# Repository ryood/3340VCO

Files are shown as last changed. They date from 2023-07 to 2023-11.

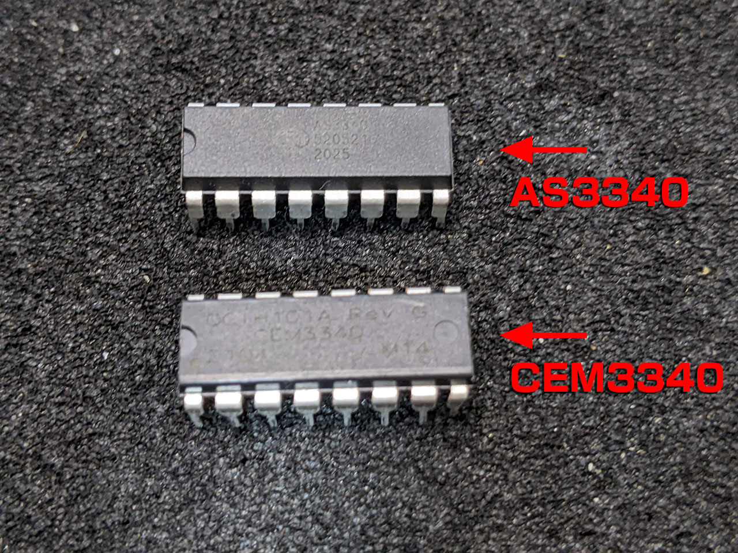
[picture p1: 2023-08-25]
3340VCO性能測定/AS3340_CEM3340.jpg

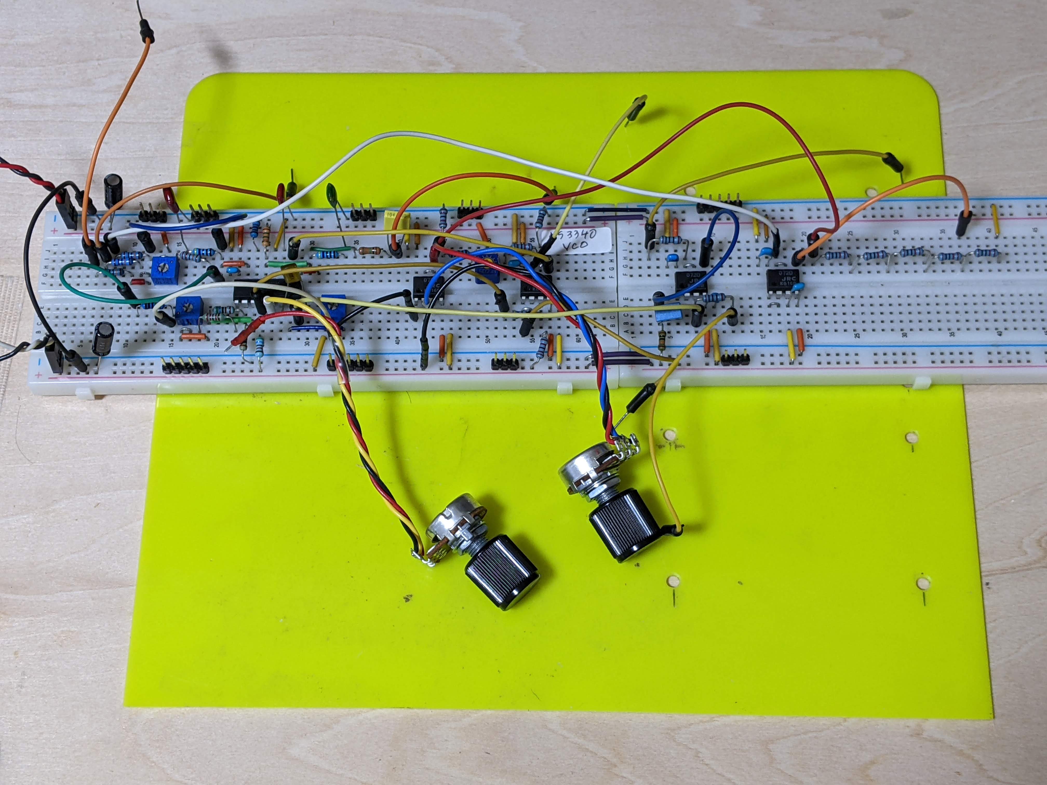
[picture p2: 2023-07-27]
etc/PXL_20230715_095748776.jpg

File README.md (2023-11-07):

# 3340VCO

AS3340/CEM3340を使用したアナログVCOです。

## 機能概要

電源入力 ±12V (Eurorack電源 10Pin)

### コントロール
FINE:  -0.5オクターブ～+0.5オクターブ連続可変

OCTAVE:  +0オクターブ～+4オクターブ切り替え

MOD:  モジュレーション・レベル

PWM:  PWMレベル調整 (PULSE_WIDTH設定値～PWM入力)

PULSE_WIDTH:  パルス幅調整

### 入出力
CV_IN:  CV入力

MOD_IN:  モジュレーション入力

PWM_IN:  PWM入力

OUT:  音声出力

入力信号電圧: -5V～+5V　出力信号振幅: -4V～+4V 

## 参考記事
[音源とオーディオの電子工作（予定）：3340VCO](https://dad8893.blogspot.com/search/label/3340VCO)

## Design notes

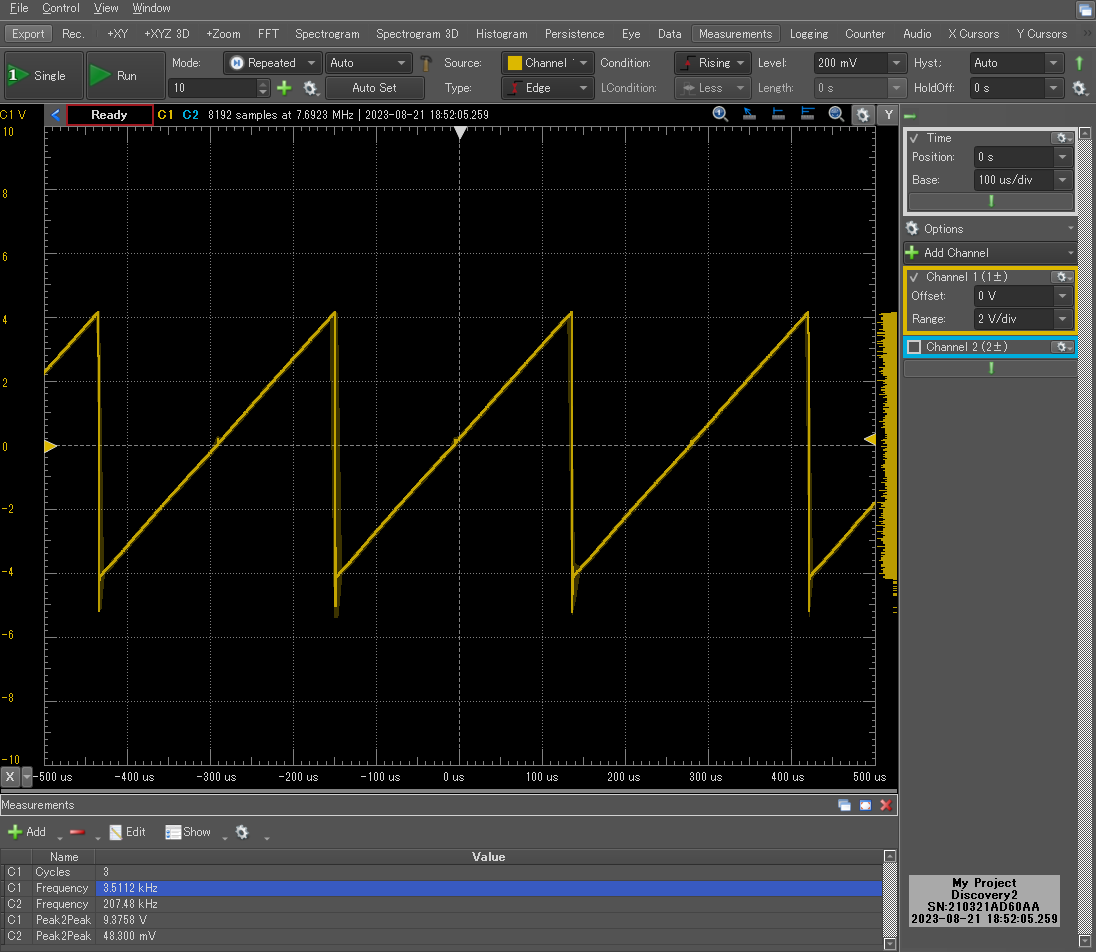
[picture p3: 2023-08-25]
3340VCO性能測定/3340VCO_SAW_3.52kHz.png

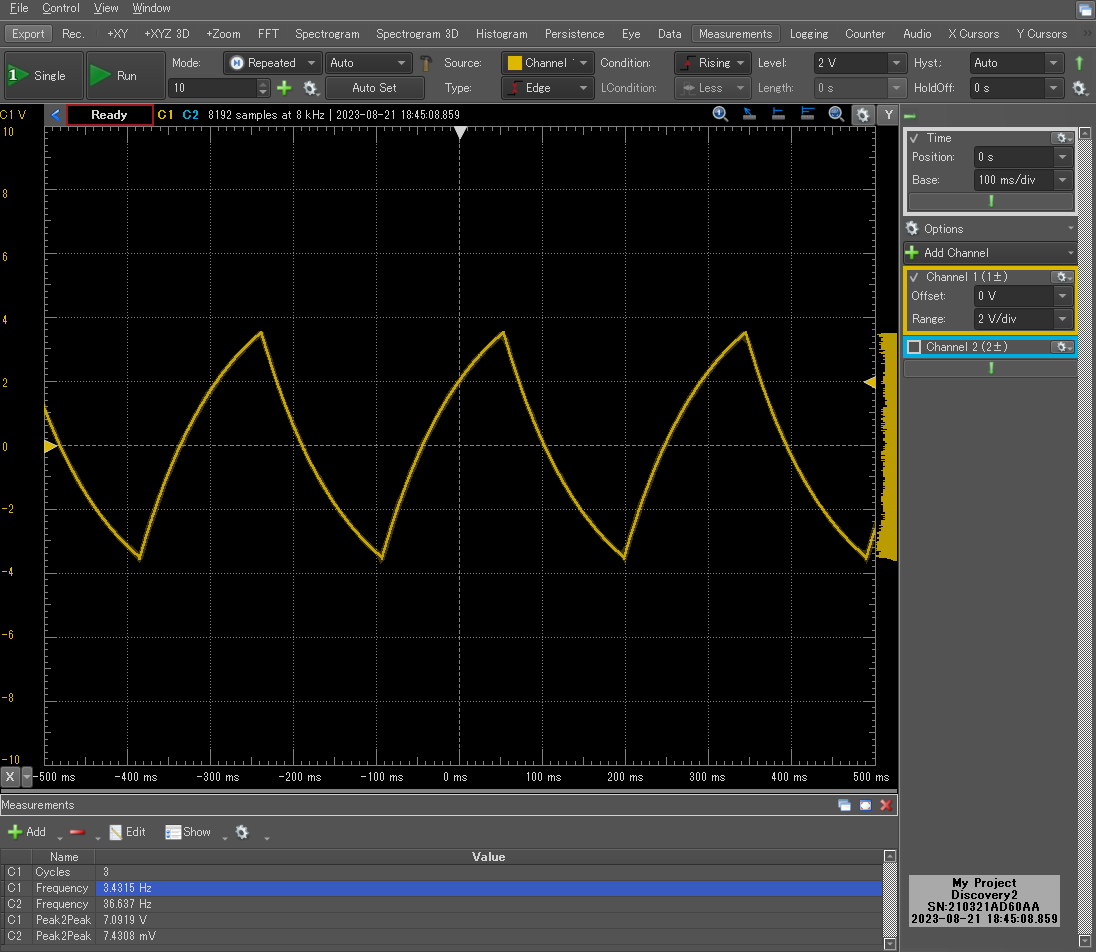
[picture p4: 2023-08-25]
3340VCO性能測定/3340VCO_TRI_3.43Hz.png

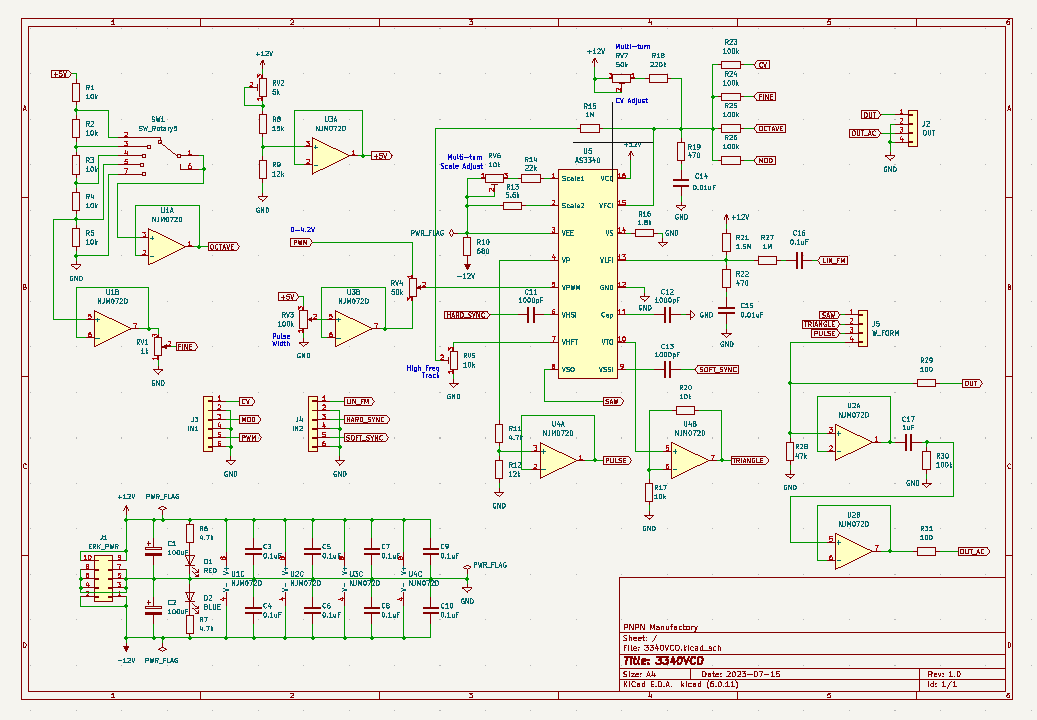
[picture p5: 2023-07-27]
etc/スクリーンショット 2023-07-15 185359.png

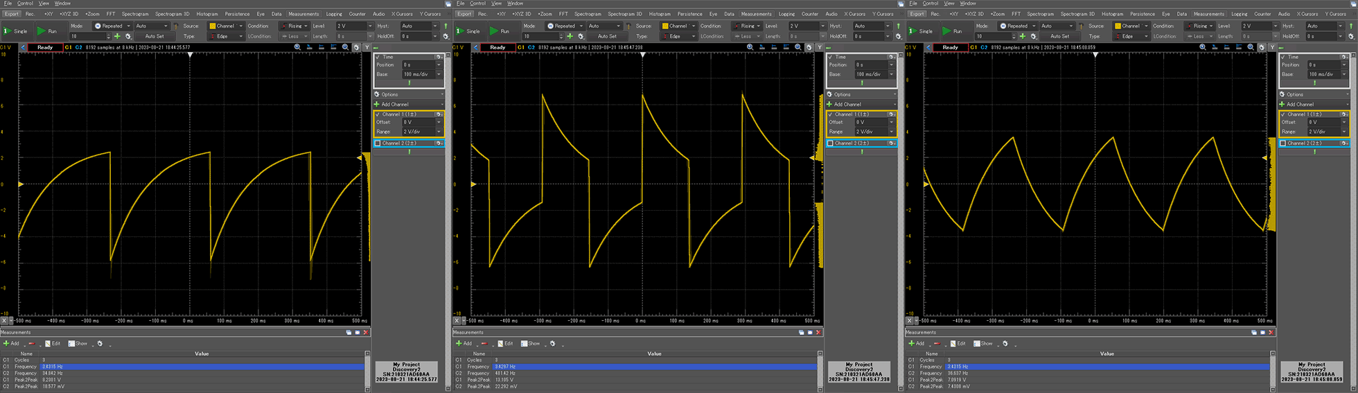
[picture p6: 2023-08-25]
3340VCO性能測定/AC_CPL.png

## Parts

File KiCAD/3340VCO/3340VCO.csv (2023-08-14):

Source: | D:\Develop\3340VCO\KiCAD\3340VCO\3340VCO.kicad_sch
Date: | 2023/08/03 16:24:58
Tool: | Eeschema (6.0.11)
Generator: | C:\Program Files\KiCad\6.0\bin\scripting\plugins/bom_csv_grouped_by_value_with_fp.py
Component Count: | 79
Ref | Qnty | Value | Cmp name | Footprint | Description | Vendor
C1, C2, | 2 | 100uF | C_Polarized | Capacitor_THT:CP_Radial_D6.3mm_P2.50mm | Polarized capacitor
C3, C4, C5, C6, C7, C8, C9, C10, | 8 | 0.1uF | C | Capacitor_THT:C_Disc_D3.0mm_W1.6mm_P2.50mm | Unpolarized capacitor
C11, C13, | 2 | 1000pF | C | Capacitor_THT:C_Rect_L7.0mm_W2.0mm_P5.00mm | Unpolarized capacitor
C12, | 1 | 1000pF/PP | C | Capacitor_THT:C_Rect_L7.0mm_W2.0mm_P5.00mm | Unpolarized capacitor
C14, C15, | 2 | 0.01uF | C | Capacitor_THT:C_Rect_L7.0mm_W3.5mm_P5.00mm | Unpolarized capacitor
C16, | 1 | 0.1uF | C | Capacitor_THT:C_Rect_L7.0mm_W3.5mm_P5.00mm | Unpolarized capacitor
C17, | 1 | 1uF | C | Capacitor_THT:C_Rect_L7.0mm_W6.0mm_P5.00mm | Unpolarized capacitor
D1, | 1 | RED | LED | LED_THT:LED_D3.0mm | Light emitting diode
D2, | 1 | BLUE | LED | LED_THT:LED_D3.0mm | Light emitting diode
H1, H2, H3, H4, | 4 | MountingHole | MountingHole | MountingHole:MountingHole_3.2mm_M3 | Mounting Hole without connection
J1, | 1 | CV_IN | Conn_01x02 | Connector_JST:JST_XH_B2B-XH-A_1x02_P2.50mm_Vertical | Generic connector, single row, 01x02, script generated (kicad-library-utils/schlib/autogen/connector/)
J2, | 1 | ERK_PWR | Conn_02x05_Odd_Even | Connector_IDC:IDC-Header_2x05_P2.54mm_Vertical | Generic connector, double row, 02x05, odd/even pin numbering scheme (row 1 odd numbers, row 2 even numbers), script generated (kicad-library-utils/schlib/autogen/connector/)
J3, | 1 | MOD_IN | Conn_01x04 | Connector_JST:JST_XH_B4B-XH-A_1x04_P2.50mm_Vertical | Generic connector, single row, 01x04, script generated (kicad-library-utils/schlib/autogen/connector/)
J4, | 1 | EXT | Conn_01x06 | Connector_JST:JST_XH_B6B-XH-A_1x06_P2.50mm_Vertical | Generic connector, single row, 01x06, script generated (kicad-library-utils/schlib/autogen/connector/)
J5, | 1 | W_FORM | Conn_01x04 | Connector_JST:JST_XH_B4B-XH-A_1x04_P2.50mm_Vertical | Generic connector, single row, 01x04, script generated (kicad-library-utils/schlib/autogen/connector/)
J6, J7, J9, | 3 | TP_GND | Conn_01x02 | Connector_PinHeader_2.54mm:PinHeader_1x02_P2.54mm_Vertical | Generic connector, single row, 01x02, script generated (kicad-library-utils/schlib/autogen/connector/)
J8, | 1 | OUT | Conn_01x02 | Connector_JST:JST_XH_B2B-XH-A_1x02_P2.50mm_Vertical | Generic connector, single row, 01x02, script generated (kicad-library-utils/schlib/autogen/connector/)
R1, R2, R3, R4, R5, R17, R18, | 7 | 10k | R | Resistor_THT:R_Axial_DIN0207_L6.3mm_D2.5mm_P10.16mm_Horizontal | Resistor
R6, R7, R10, | 3 | 4.7k | R | Resistor_THT:R_Axial_DIN0207_L6.3mm_D2.5mm_P10.16mm_Horizontal | Resistor
R8, | 1 | 15k | R | Resistor_THT:R_Axial_DIN0207_L6.3mm_D2.5mm_P10.16mm_Horizontal | Resistor
R9, R11, | 2 | 12k | R | Resistor_THT:R_Axial_DIN0207_L6.3mm_D2.5mm_P10.16mm_Horizontal | Resistor
R12, | 1 | 22k | R | Resistor_THT:R_Axial_DIN0207_L6.3mm_D2.5mm_P10.16mm_Horizontal | Resistor
R13, | 1 | 5.6k | R | Resistor_THT:R_Axial_DIN0207_L6.3mm_D2.5mm_P10.16mm_Horizontal | Resistor
R14, | 1 | 680 | R | Resistor_THT:R_Axial_DIN0207_L6.3mm_D2.5mm_P10.16mm_Horizontal | Resistor
R15, | 1 | 270k | R | Resistor_THT:R_Axial_DIN0207_L6.3mm_D2.5mm_P10.16mm_Horizontal | Resistor
R16, R27, | 2 | 1M | R | Resistor_THT:R_Axial_DIN0207_L6.3mm_D2.5mm_P10.16mm_Horizontal | Resistor
R19, R20, R21, R22, R30, | 5 | 100k | R | Resistor_THT:R_Axial_DIN0207_L6.3mm_D2.5mm_P10.16mm_Horizontal | Resistor
R23, R26, | 2 | 470 | R | Resistor_THT:R_Axial_DIN0207_L6.3mm_D2.5mm_P10.16mm_Horizontal | Resistor
R24, | 1 | 1.8k | R | Resistor_THT:R_Axial_DIN0207_L6.3mm_D2.5mm_P10.16mm_Horizontal | Resistor
R25, | 1 | 1.5M | R | Resistor_THT:R_Axial_DIN0207_L6.3mm_D2.5mm_P10.16mm_Horizontal | Resistor
R28, | 1 | 47k | R | Resistor_THT:R_Axial_DIN0207_L6.3mm_D2.5mm_P10.16mm_Horizontal | Resistor
R29, | 1 | 100 | R | Resistor_THT:R_Axial_DIN0207_L6.3mm_D2.5mm_P10.16mm_Horizontal | Resistor
RV1, | 1 | 1k | R_Potentiometer | Potentiometer_THT:Potentiometer_Alps_RK09Y11_Single_Horizontal | Potentiometer
RV2, | 1 | 5k | R_Potentiometer_Trim | myfootprint:Potentiometer_Bourns_3362P_Vertical | Trim-potentiometer
RV3, RV4, RV8, | 3 | 50k | R_Potentiometer | Potentiometer_THT:Potentiometer_Alps_RK09Y11_Single_Horizontal | Potentiometer
RV5, | 1 | 100k | R_Potentiometer_Trim | myfootprint:Potentiometer_Bourns_3362P_Vertical | Trim-potentiometer
RV6, | 1 | 10k | R_Potentiometer_Trim | Potentiometer_THT:Potentiometer_Bourns_3296W_Vertical | Trim-potentiometer
RV7, | 1 | 100k | R_Potentiometer_Trim | Potentiometer_THT:Potentiometer_Bourns_3296W_Vertical | Trim-potentiometer
SW1, | 1 | SW_Rotary5 | SW_Rotary5 | myfootprint:Rotary_Ecoder_Ali_Jtom | 1 rotary switch with 5 positions
TP1, | 1 | +5V | TestPoint | TestPoint:TestPoint_Pad_D1.0mm | test point
TP2, | 1 | +1V | TestPoint | TestPoint:TestPoint_Pad_D1.0mm | test point
TP3, | 1 | OCT | TestPoint | TestPoint:TestPoint_Pad_D1.0mm | test point
U1, U2, U3, U4, | 4 | NJM072D | TL072 | Package_DIP:DIP-8_W7.62mm_Socket | Dual Low-Noise JFET-Input Operational Amplifiers, DIP-8/SOIC-8
U5, | 1 | AS3340 | AS3340 | Package_DIP:DIP-16_W7.62mm_Socket | Voltage Controlled Oscillator (VCO)

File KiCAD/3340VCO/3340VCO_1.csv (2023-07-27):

Source: | D:\Develop\3340VCO\KiCAD\3340VCO\3340VCO.kicad_sch
Date: | 2023/07/24 16:57:43
Tool: | Eeschema (6.0.11)
Generator: | C:\Program Files\KiCad\6.0\bin\scripting\plugins/bom_csv_grouped_by_value.py
Component Count: | 77
Individual Components:
Item | Qty | Reference(s) | Value | LibPart | Footprint | Datasheet
 |  | C1 | 100uF | Device:C_Polarized | Capacitor_THT:CP_Radial_D6.3mm_P2.50mm | ~
 |  | C2 | 100uF | Device:C_Polarized | Capacitor_THT:CP_Radial_D6.3mm_P2.50mm | ~
 |  | C3 | 0.1uF | Device:C | Capacitor_THT:C_Disc_D3.0mm_W1.6mm_P2.50mm | ~
 |  | C4 | 0.1uF | Device:C | Capacitor_THT:C_Disc_D3.0mm_W1.6mm_P2.50mm | ~
 |  | C5 | 0.1uF | Device:C | Capacitor_THT:C_Disc_D3.0mm_W1.6mm_P2.50mm | ~
 |  | C6 | 0.1uF | Device:C | Capacitor_THT:C_Disc_D3.0mm_W1.6mm_P2.50mm | ~
 |  | C7 | 0.1uF | Device:C | Capacitor_THT:C_Disc_D3.0mm_W1.6mm_P2.50mm | ~
 |  | C8 | 0.1uF | Device:C | Capacitor_THT:C_Disc_D3.0mm_W1.6mm_P2.50mm | ~
 |  | C9 | 0.1uF | Device:C | Capacitor_THT:C_Disc_D3.0mm_W1.6mm_P2.50mm | ~
 |  | C10 | 0.1uF | Device:C | Capacitor_THT:C_Disc_D3.0mm_W1.6mm_P2.50mm | ~
 |  | C11 | 1000pF | Device:C | Capacitor_THT:C_Rect_L7.0mm_W2.0mm_P5.00mm | ~
 |  | C12 | 1000pF | Device:C | Capacitor_THT:C_Rect_L7.0mm_W2.0mm_P5.00mm | ~
 |  | C13 | 1000pF | Device:C | Capacitor_THT:C_Rect_L7.0mm_W2.0mm_P5.00mm | ~
 |  | C14 | 0.01uF | Device:C | Capacitor_THT:C_Rect_L7.0mm_W3.5mm_P5.00mm | ~
 |  | C15 | 0.01uF | Device:C | Capacitor_THT:C_Rect_L7.0mm_W3.5mm_P5.00mm | ~
 |  | C16 | 0.1uF | Device:C | Capacitor_THT:C_Rect_L7.0mm_W2.5mm_P5.00mm | ~
 |  | C17 | 1uF | Device:C | Capacitor_THT:C_Rect_L7.0mm_W6.0mm_P5.00mm | ~
 |  | D1 | RED | Device:LED | LED_THT:LED_D3.0mm | ~
 |  | D2 | BLUE | Device:LED | LED_THT:LED_D3.0mm | ~
 |  | H1 | MountingHole | Mechanical:MountingHole | MountingHole:MountingHole_3.2mm_M3 | ~
 |  | H2 | MountingHole | Mechanical:MountingHole | MountingHole:MountingHole_3.2mm_M3 | ~
 |  | H3 | MountingHole | Mechanical:MountingHole | MountingHole:MountingHole_3.2mm_M3 | ~
 |  | H4 | MountingHole | Mechanical:MountingHole | MountingHole:MountingHole_3.2mm_M3 | ~
 |  | J1 | CV_IN | Connector_Generic:Conn_01x02 | Connector_JST:JST_XH_B2B-XH-A_1x02_P2.50mm_Vertical | ~
 |  | J2 | ERK_PWR | Connector_Generic:Conn_02x05_Odd_Even | Connector_IDC:IDC-Header_2x05_P2.54mm_Vertical | ~
 |  | J3 | MOD_IN | Connector_Generic:Conn_01x04 | Connector_JST:JST_XH_B4B-XH-A_1x04_P2.50mm_Vertical | ~
 |  | J4 | IN2 | Connector_Generic:Conn_01x06 | Connector_JST:JST_XH_B6B-XH-A_1x06_P2.50mm_Vertical | ~
 |  | J5 | W_FORM | Connector_Generic:Conn_01x04 | Connector_JST:JST_XH_B4B-XH-A_1x04_P2.50mm_Vertical | ~
 |  | J6 | TP_GND | Connector_Generic:Conn_01x02 | Connector_PinHeader_2.54mm:PinHeader_1x02_P2.54mm_Vertical | ~
 |  | J7 | TP_GND | Connector_Generic:Conn_01x02 | Connector_PinHeader_2.54mm:PinHeader_1x02_P2.54mm_Vertical | ~
 |  | J8 | OUT | Connector_Generic:Conn_01x02 | Connector_JST:JST_XH_B2B-XH-A_1x02_P2.50mm_Vertical | ~
 |  | J9 | TP_GND | Connector_Generic:Conn_01x02 | Connector_PinHeader_2.54mm:PinHeader_1x02_P2.54mm_Vertical | ~
 |  | R1 | 10k | Device:R | Resistor_THT:R_Axial_DIN0207_L6.3mm_D2.5mm_P10.16mm_Horizontal | ~
 |  | R2 | 10k | Device:R | Resistor_THT:R_Axial_DIN0207_L6.3mm_D2.5mm_P10.16mm_Horizontal | ~
 |  | R3 | 10k | Device:R | Resistor_THT:R_Axial_DIN0207_L6.3mm_D2.5mm_P10.16mm_Horizontal | ~
 |  | R4 | 10k | Device:R | Resistor_THT:R_Axial_DIN0207_L6.3mm_D2.5mm_P10.16mm_Horizontal | ~
 |  | R5 | 10k | Device:R | Resistor_THT:R_Axial_DIN0207_L6.3mm_D2.5mm_P10.16mm_Horizontal | ~
 |  | R6 | 4.7k | Device:R | Resistor_THT:R_Axial_DIN0207_L6.3mm_D2.5mm_P10.16mm_Horizontal | ~
 |  | R7 | 4.7k | Device:R | Resistor_THT:R_Axial_DIN0207_L6.3mm_D2.5mm_P10.16mm_Horizontal | ~
 |  | R8 | 15k | Device:R | Resistor_THT:R_Axial_DIN0207_L6.3mm_D2.5mm_P10.16mm_Horizontal | ~
 |  | R9 | 12k | Device:R | Resistor_THT:R_Axial_DIN0207_L6.3mm_D2.5mm_P10.16mm_Horizontal | ~
 |  | R10 | 4.7k | Device:R | Resistor_THT:R_Axial_DIN0207_L6.3mm_D2.5mm_P10.16mm_Horizontal | ~
 |  | R11 | 12k | Device:R | Resistor_THT:R_Axial_DIN0207_L6.3mm_D2.5mm_P10.16mm_Horizontal | ~
 |  | R12 | 22k | Device:R | Resistor_THT:R_Axial_DIN0207_L6.3mm_D2.5mm_P10.16mm_Horizontal | ~
 |  | R13 | 5.6k | Device:R | Resistor_THT:R_Axial_DIN0207_L6.3mm_D2.5mm_P10.16mm_Horizontal | ~
 |  | R14 | 680 | Device:R | Resistor_THT:R_Axial_DIN0207_L6.3mm_D2.5mm_P10.16mm_Horizontal | ~
 |  | R15 | 220k | Device:R | Resistor_THT:R_Axial_DIN0207_L6.3mm_D2.5mm_P10.16mm_Horizontal | ~
 |  | R16 | 1M | Device:R | Resistor_THT:R_Axial_DIN0207_L6.3mm_D2.5mm_P10.16mm_Horizontal | ~
 |  | R17 | 10k | Device:R | Resistor_THT:R_Axial_DIN0207_L6.3mm_D2.5mm_P10.16mm_Horizontal | ~
 |  | R18 | 10k | Device:R | Resistor_THT:R_Axial_DIN0207_L6.3mm_D2.5mm_P10.16mm_Horizontal | ~
 |  | R19 | 100k | Device:R | Resistor_THT:R_Axial_DIN0207_L6.3mm_D2.5mm_P10.16mm_Horizontal | ~
 |  | R20 | 100k | Device:R | Resistor_THT:R_Axial_DIN0207_L6.3mm_D2.5mm_P10.16mm_Horizontal | ~
 |  | R21 | 100k | Device:R | Resistor_THT:R_Axial_DIN0207_L6.3mm_D2.5mm_P10.16mm_Horizontal | ~
 |  | R22 | 100k | Device:R | Resistor_THT:R_Axial_DIN0207_L6.3mm_D2.5mm_P10.16mm_Horizontal | ~
 |  | R23 | 470 | Device:R | Resistor_THT:R_Axial_DIN0207_L6.3mm_D2.5mm_P10.16mm_Horizontal | ~
 |  | R24 | 1.8k | Device:R | Resistor_THT:R_Axial_DIN0207_L6.3mm_D2.5mm_P10.16mm_Horizontal | ~
 |  | R25 | 1.5M | Device:R | Resistor_THT:R_Axial_DIN0207_L6.3mm_D2.5mm_P10.16mm_Horizontal | ~
 |  | R26 | 470 | Device:R | Resistor_THT:R_Axial_DIN0207_L6.3mm_D2.5mm_P10.16mm_Horizontal | ~
 |  | R27 | 1M | Device:R | Resistor_THT:R_Axial_DIN0207_L6.3mm_D2.5mm_P10.16mm_Horizontal | ~
 |  | R28 | 47k | Device:R | Resistor_THT:R_Axial_DIN0207_L6.3mm_D2.5mm_P10.16mm_Horizontal | ~
 |  | R29 | 100 | Device:R | Resistor_THT:R_Axial_DIN0207_L6.3mm_D2.5mm_P10.16mm_Horizontal | ~
 |  | R30 | 100k | Device:R | Resistor_THT:R_Axial_DIN0207_L6.3mm_D2.5mm_P10.16mm_Horizontal | ~
 |  | RV1 | 1k | Device:R_Potentiometer | Potentiometer_THT:Potentiometer_Alps_RK09Y11_Single_Horizontal | ~
 |  | RV2 | 5k | Device:R_Potentiometer_Trim | myfootprint:Potentiometer_Bourns_3362P_Vertical | ~
 |  | RV3 | 100k | Device:R_Potentiometer | Potentiometer_THT:Potentiometer_Alps_RK09Y11_Single_Horizontal | ~
 |  | RV4 | 50k | Device:R_Potentiometer | Potentiometer_THT:Potentiometer_Alps_RK09Y11_Single_Horizontal | ~
 |  | RV5 | 100k | Device:R_Potentiometer_Trim | myfootprint:Potentiometer_Bourns_3362P_Vertical | ~
 |  | RV6 | 10k | Device:R_Potentiometer_Trim | Potentiometer_THT:Potentiometer_Bourns_3296W_Vertical | ~
 |  | RV7 | 50k | Device:R_Potentiometer_Trim | Potentiometer_THT:Potentiometer_Bourns_3296W_Vertical | ~
 |  | RV8 | 50k | Device:R_Potentiometer | Potentiometer_THT:Potentiometer_Alps_RK09Y11_Single_Horizontal | ~
 |  | SW1 | SW_Rotary5 | My_Device:SW_Rotary5 | myfootprint:Rotary_Ecoder_Ali_Jtom
 |  | TP1 | +5V | Connector:TestPoint | TestPoint:TestPoint_Pad_D1.0mm | ~
 |  | U1 | NJM072D | Amplifier_Operational:TL072 | Package_DIP:DIP-8_W7.62mm_Socket | http://www.ti.com/lit/ds/symlink/tl071.pdf
 |  | U2 | NJM072D | Amplifier_Operational:TL072 | Package_DIP:DIP-8_W7.62mm_Socket | http://www.ti.com/lit/ds/symlink/tl071.pdf
 |  | U3 | NJM072D | Amplifier_Operational:TL072 | Package_DIP:DIP-8_W7.62mm_Socket | http://www.ti.com/lit/ds/symlink/tl071.pdf
 |  | U4 | NJM072D | Amplifier_Operational:TL072 | Package_DIP:DIP-8_W7.62mm_Socket | http://www.ti.com/lit/ds/symlink/tl071.pdf
 |  | U5 | AS3340 | My_Device0:AS3340 | Package_DIP:DIP-16_W7.62mm_Socket
Collated Components:
Item | Qty | Reference(s) | Value | LibPart | Footprint | Datasheet
1 | 2 | C1, C2 | 100uF | Device:C_Polarized | Capacitor_THT:CP_Radial_D6.3mm_P2.50mm | ~
2 | 8 | C3, C4, C5, C6, C7, C8, C9, C10 | 0.1uF | Device:C | Capacitor_THT:C_Disc_D3.0mm_W1.6mm_P2.50mm | ~
3 | 3 | C11, C12, C13 | 1000pF | Device:C | Capacitor_THT:C_Rect_L7.0mm_W2.0mm_P5.00mm | ~
4 | 2 | C14, C15 | 0.01uF | Device:C | Capacitor_THT:C_Rect_L7.0mm_W3.5mm_P5.00mm | ~
5 | 1 | C16 | 0.1uF | Device:C | Capacitor_THT:C_Rect_L7.0mm_W2.5mm_P5.00mm | ~
6 | 1 | C17 | 1uF | Device:C | Capacitor_THT:C_Rect_L7.0mm_W6.0mm_P5.00mm | ~
7 | 1 | D1 | RED | Device:LED | LED_THT:LED_D3.0mm | ~
8 | 1 | D2 | BLUE | Device:LED | LED_THT:LED_D3.0mm | ~
9 | 4 | H1, H2, H3, H4 | MountingHole | Mechanical:MountingHole | MountingHole:MountingHole_3.2mm_M3 | ~
10 | 1 | J1 | CV_IN | Connector_Generic:Conn_01x02 | Connector_JST:JST_XH_B2B-XH-A_1x02_P2.50mm_Vertical | ~
11 | 1 | J2 | ERK_PWR | Connector_Generic:Conn_02x05_Odd_Even | Connector_IDC:IDC-Header_2x05_P2.54mm_Vertical | ~
12 | 1 | J3 | MOD_IN | Connector_Generic:Conn_01x04 | Connector_JST:JST_XH_B4B-XH-A_1x04_P2.50mm_Vertical | ~
13 | 1 | J4 | IN2 | Connector_Generic:Conn_01x06 | Connector_JST:JST_XH_B6B-XH-A_1x06_P2.50mm_Vertical | ~
14 | 1 | J5 | W_FORM | Connector_Generic:Conn_01x04 | Connector_JST:JST_XH_B4B-XH-A_1x04_P2.50mm_Vertical | ~
15 | 3 | J6, J7, J9 | TP_GND | Connector_Generic:Conn_01x02 | Connector_PinHeader_2.54mm:PinHeader_1x02_P2.54mm_Vertical | ~
16 | 1 | J8 | OUT | Connector_Generic:Conn_01x02 | Connector_JST:JST_XH_B2B-XH-A_1x02_P2.50mm_Vertical | ~
17 | 7 | R1, R2, R3, R4, R5, R17, R18 | 10k | Device:R | Resistor_THT:R_Axial_DIN0207_L6.3mm_D2.5mm_P10.16mm_Horizontal | ~
18 | 3 | R6, R7, R10 | 4.7k | Device:R | Resistor_THT:R_Axial_DIN0207_L6.3mm_D2.5mm_P10.16mm_Horizontal | ~
19 | 1 | R8 | 15k | Device:R | Resistor_THT:R_Axial_DIN0207_L6.3mm_D2.5mm_P10.16mm_Horizontal | ~
20 | 2 | R9, R11 | 12k | Device:R | Resistor_THT:R_Axial_DIN0207_L6.3mm_D2.5mm_P10.16mm_Horizontal | ~
21 | 1 | R12 | 22k | Device:R | Resistor_THT:R_Axial_DIN0207_L6.3mm_D2.5mm_P10.16mm_Horizontal | ~
22 | 1 | R13 | 5.6k | Device:R | Resistor_THT:R_Axial_DIN0207_L6.3mm_D2.5mm_P10.16mm_Horizontal | ~
23 | 1 | R14 | 680 | Device:R | Resistor_THT:R_Axial_DIN0207_L6.3mm_D2.5mm_P10.16mm_Horizontal | ~
24 | 1 | R15 | 220k | Device:R | Resistor_THT:R_Axial_DIN0207_L6.3mm_D2.5mm_P10.16mm_Horizontal | ~
25 | 2 | R16, R27 | 1M | Device:R | Resistor_THT:R_Axial_DIN0207_L6.3mm_D2.5mm_P10.16mm_Horizontal | ~
26 | 5 | R19, R20, R21, R22, R30 | 100k | Device:R | Resistor_THT:R_Axial_DIN0207_L6.3mm_D2.5mm_P10.16mm_Horizontal | ~
27 | 2 | R23, R26 | 470 | Device:R | Resistor_THT:R_Axial_DIN0207_L6.3mm_D2.5mm_P10.16mm_Horizontal | ~
28 | 1 | R24 | 1.8k | Device:R | Resistor_THT:R_Axial_DIN0207_L6.3mm_D2.5mm_P10.16mm_Horizontal | ~
29 | 1 | R25 | 1.5M | Device:R | Resistor_THT:R_Axial_DIN0207_L6.3mm_D2.5mm_P10.16mm_Horizontal | ~
30 | 1 | R28 | 47k | Device:R | Resistor_THT:R_Axial_DIN0207_L6.3mm_D2.5mm_P10.16mm_Horizontal | ~
31 | 1 | R29 | 100 | Device:R | Resistor_THT:R_Axial_DIN0207_L6.3mm_D2.5mm_P10.16mm_Horizontal | ~
32 | 1 | RV1 | 1k | Device:R_Potentiometer | Potentiometer_THT:Potentiometer_Alps_RK09Y11_Single_Horizontal | ~
33 | 1 | RV2 | 5k | Device:R_Potentiometer_Trim | myfootprint:Potentiometer_Bourns_3362P_Vertical | ~
34 | 1 | RV3 | 100k | Device:R_Potentiometer | Potentiometer_THT:Potentiometer_Alps_RK09Y11_Single_Horizontal | ~
35 | 2 | RV4, RV8 | 50k | Device:R_Potentiometer | Potentiometer_THT:Potentiometer_Alps_RK09Y11_Single_Horizontal | ~
36 | 1 | RV5 | 100k | Device:R_Potentiometer_Trim | myfootprint:Potentiometer_Bourns_3362P_Vertical | ~
37 | 1 | RV6 | 10k | Device:R_Potentiometer_Trim | Potentiometer_THT:Potentiometer_Bourns_3296W_Vertical | ~
38 | 1 | RV7 | 50k | Device:R_Potentiometer_Trim | Potentiometer_THT:Potentiometer_Bourns_3296W_Vertical | ~
39 | 1 | SW1 | SW_Rotary5 | My_Device:SW_Rotary5 | myfootprint:Rotary_Ecoder_Ali_Jtom
40 | 1 | TP1 | +5V | Connector:TestPoint | TestPoint:TestPoint_Pad_D1.0mm | ~
41 | 4 | U1, U2, U3, U4 | NJM072D | Amplifier_Operational:TL072 | Package_DIP:DIP-8_W7.62mm_Socket | http://www.ti.com/lit/ds/symlink/tl071.pdf
42 | 1 | U5 | AS3340 | My_Device0:AS3340 | Package_DIP:DIP-16_W7.62mm_Socket

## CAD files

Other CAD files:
CAD/3340VCO_panel_EXT.dwg
CAD/3340VCO_panel.dwg
CAD/3340VCO_panel_sunpo.dwg

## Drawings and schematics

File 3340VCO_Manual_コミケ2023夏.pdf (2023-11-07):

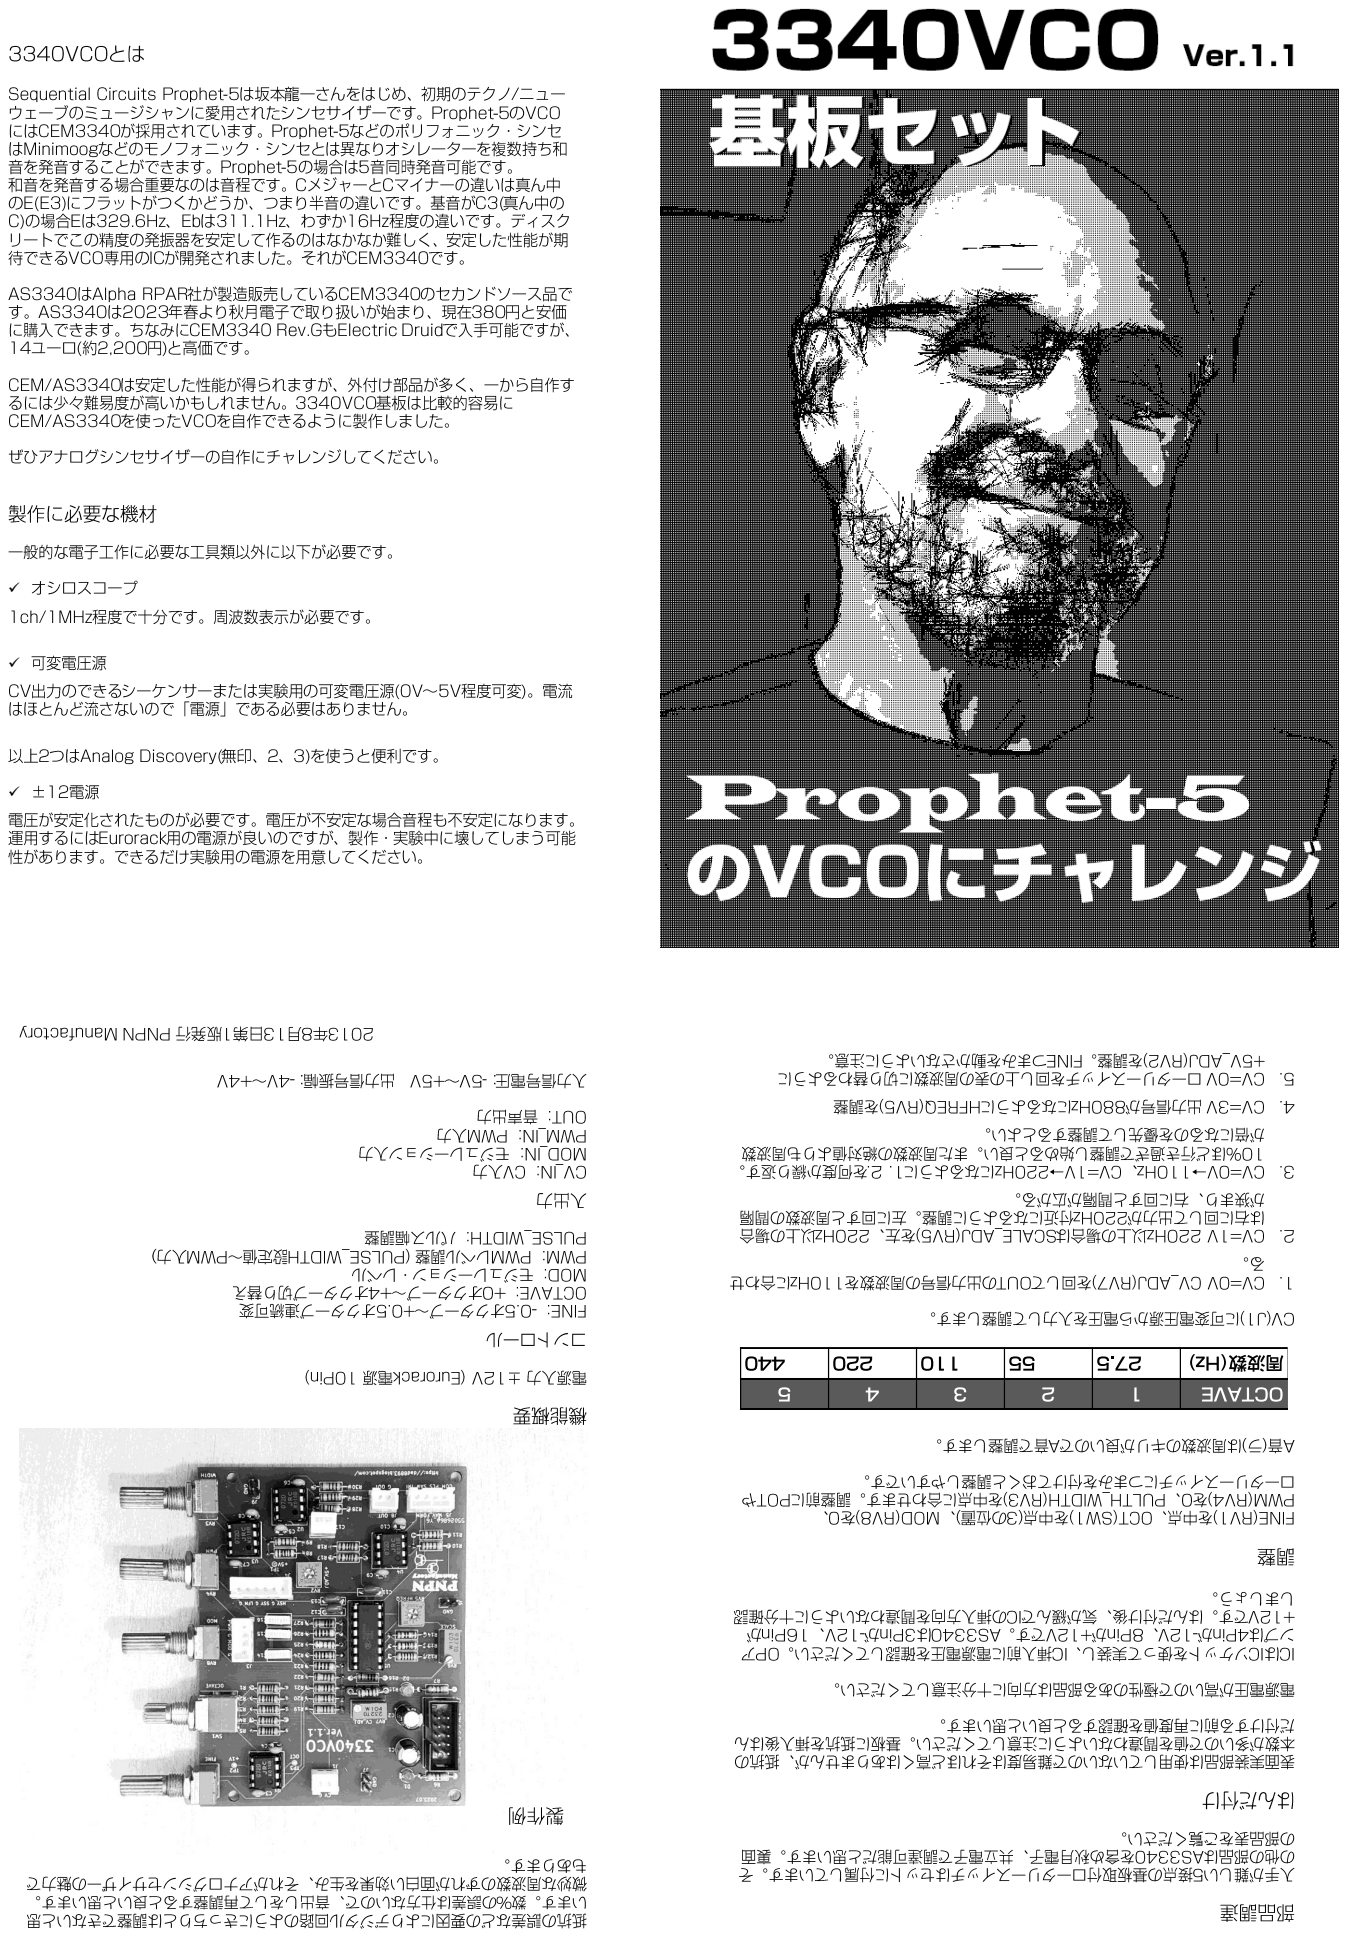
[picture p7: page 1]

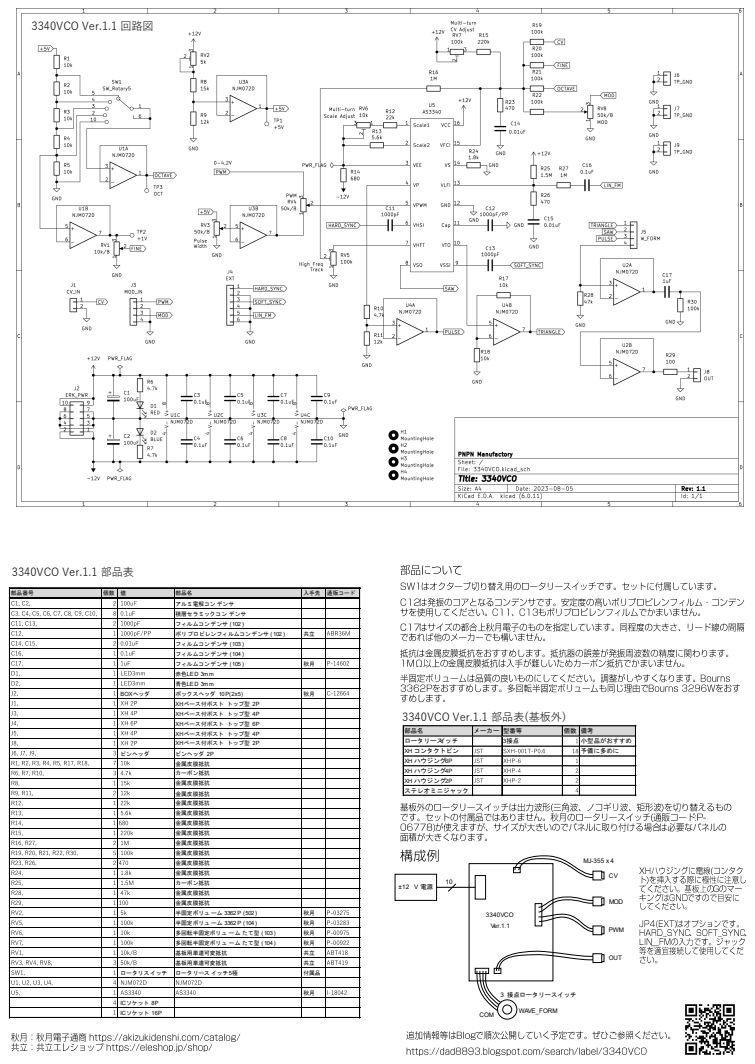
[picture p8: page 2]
3340VCO Ver.1.1 回路図; 3340VCO Ver.1.1 部品表

3340VCO Ver.1.1 部品表(基板外)

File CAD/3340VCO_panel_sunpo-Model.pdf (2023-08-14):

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

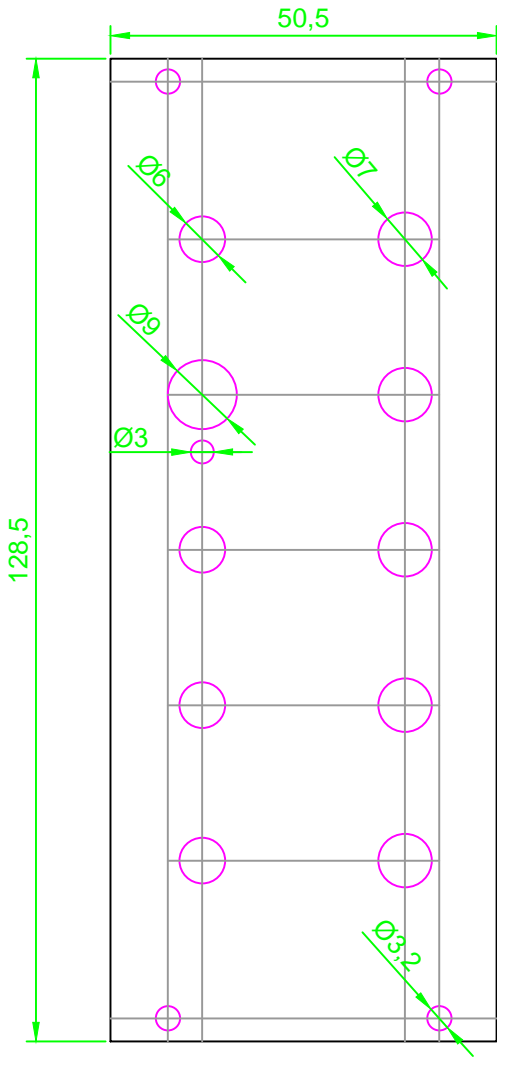
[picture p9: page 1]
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

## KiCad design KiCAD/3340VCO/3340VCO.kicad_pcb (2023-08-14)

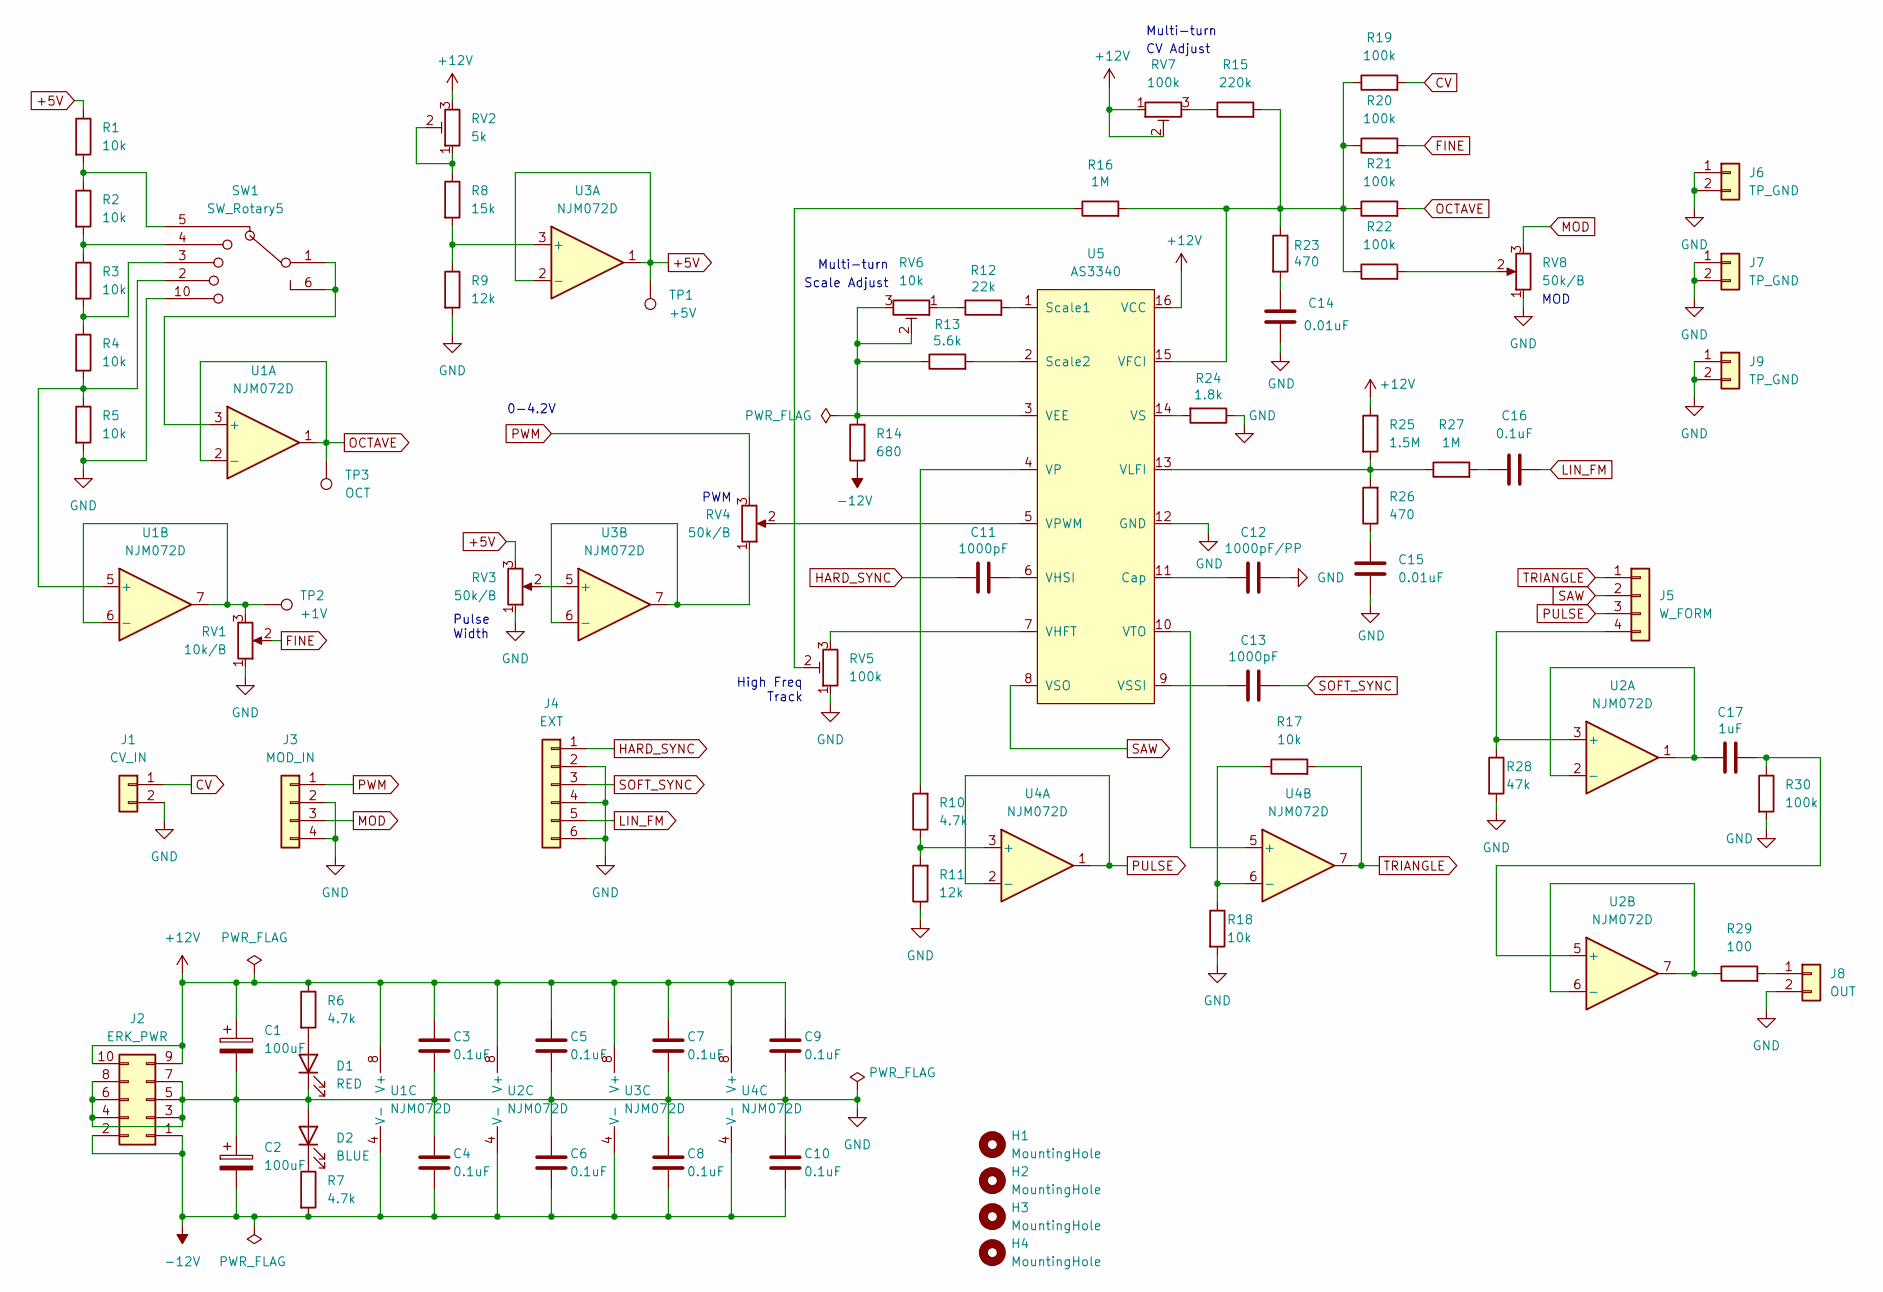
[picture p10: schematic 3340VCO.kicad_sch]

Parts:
C1, C2: 100uF; CP_Radial_D6.3mm_P2.50mm
C3, C4, C5, C6, C7, C8, C9, C10: 0.1uF; C_Disc_D3.0mm_W1.6mm_P2.50mm
C11, C13: 1000pF; C_Rect_L7.0mm_W2.0mm_P5.00mm
C12: 1000pF/PP; C_Rect_L7.0mm_W2.0mm_P5.00mm
C14, C15: 0.01uF; C_Rect_L7.0mm_W3.5mm_P5.00mm
C16: 0.1uF; C_Rect_L7.0mm_W3.5mm_P5.00mm
C17: 1uF; C_Rect_L7.0mm_W6.0mm_P5.00mm
D1: RED; LED_D3.0mm
D2: BLUE; LED_D3.0mm
H1, H2, H3, H4: MountingHole; MountingHole_3.2mm_M3
J1: CV_IN; JST_XH_B2B-XH-A_1x02_P2.50mm_Vertical
J2: ERK_PWR; IDC-Header_2x05_P2.54mm_Vertical
J3: MOD_IN; JST_XH_B4B-XH-A_1x04_P2.50mm_Vertical
J4: EXT; JST_XH_B6B-XH-A_1x06_P2.50mm_Vertical
J5: W_FORM; JST_XH_B4B-XH-A_1x04_P2.50mm_Vertical
J6, J7, J9: TP_GND; PinHeader_1x02_P2.54mm_Vertical
J8: OUT; JST_XH_B2B-XH-A_1x02_P2.50mm_Vertical
R1, R2, R3, R4, R5, R17, R18: 10k; R_Axial_DIN0207_L6.3mm_D2.5mm_P10.16mm_Horizontal
R6, R7, R10: 4.7k; R_Axial_DIN0207_L6.3mm_D2.5mm_P10.16mm_Horizontal
R8: 15k; R_Axial_DIN0207_L6.3mm_D2.5mm_P10.16mm_Horizontal
R9, R11: 12k; R_Axial_DIN0207_L6.3mm_D2.5mm_P10.16mm_Horizontal
R12: 22k; R_Axial_DIN0207_L6.3mm_D2.5mm_P10.16mm_Horizontal
R13: 5.6k; R_Axial_DIN0207_L6.3mm_D2.5mm_P10.16mm_Horizontal
R14: 680; R_Axial_DIN0207_L6.3mm_D2.5mm_P10.16mm_Horizontal
R15: 220k; R_Axial_DIN0207_L6.3mm_D2.5mm_P10.16mm_Horizontal
R16, R27: 1M; R_Axial_DIN0207_L6.3mm_D2.5mm_P10.16mm_Horizontal
R19, R20, R21, R22, R30: 100k; R_Axial_DIN0207_L6.3mm_D2.5mm_P10.16mm_Horizontal
R23, R26: 470; R_Axial_DIN0207_L6.3mm_D2.5mm_P10.16mm_Horizontal
R24: 1.8k; R_Axial_DIN0207_L6.3mm_D2.5mm_P10.16mm_Horizontal
R25: 1.5M; R_Axial_DIN0207_L6.3mm_D2.5mm_P10.16mm_Horizontal
R28: 47k; R_Axial_DIN0207_L6.3mm_D2.5mm_P10.16mm_Horizontal
R29: 100; R_Axial_DIN0207_L6.3mm_D2.5mm_P10.16mm_Horizontal
RV1: 10k/B; Potentiometer_Alps_RK09Y11_Single_Horizontal
RV2: 5k; Potentiometer_Bourns_3362P_Vertical
RV3, RV4, RV8: 50k/B; Potentiometer_Alps_RK09Y11_Single_Horizontal
RV5: 100k; Potentiometer_Bourns_3362P_Vertical
RV6: 10k; Potentiometer_Bourns_3296W_Vertical
RV7: 100k; Potentiometer_Bourns_3296W_Vertical
SW1: SW_Rotary5; Rotary_Ecoder_Ali_Jtom
TP1: +5V; TestPoint_Pad_D1.0mm
TP2: +1V; TestPoint_Pad_D1.0mm
TP3: OCT; TestPoint_Pad_D1.0mm
U1, U2, U3, U4: NJM072D; DIP-8_W7.62mm_Socket
U5: AS3340; DIP-16_W7.62mm_Socket

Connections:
+5V: R1.1, RV3.3, TP1.1, U3.1, U3.2 (-)
+12V: C1.1, C3.1, C5.1, C7.1, C9.1, J2.9, J2.10, R6.1, R25.1, RV2.3, RV7.1, RV7.2, U1.8 (V+), U2.8 (V+), U3.8 (V+), U4.8 (V+), U5.16 (VCC)
-12V: C2.2, C4.2, C6.2, C8.2, C10.2, J2.1, J2.2, R7.2, R14.1, U1.4 (V-), U2.4 (V-), U3.4 (V-), U4.4 (V-)
CV: J1.1, R19.2
FINE: R20.2, RV1.2
GND: C1.2, C2.1, C3.2, C4.1, C5.2, C6.1, C7.2, C8.1, C9.2, C10.1, C12.1, C14.2, C15.1, D1.1 (K), D2.2 (A), J1.2, J2.3, J2.4, J2.5, J2.6, J2.7, J2.8, J3.2, J3.4, J4.2, J4.4, J4.6, J6.1, J6.2, J7.1, J7.2, J8.2, J9.1, J9.2, R5.2, R9.2, R11.1, R18.2, R24.1, R28.2, R30.2, RV1.1, RV3.1, RV5.1, RV8.1, SW1.10, U5.12 (GND)
HARD_SYNC: C11.2, J4.1
LIN_FM: C16.2, J4.5
MOD: J3.3, RV8.3
unnamed: C11.1, U5.6 (VHSI)
unnamed: C12.2, U5.11 (Cap)
unnamed: C13.2, U5.9 (VSSI)
unnamed: C14.1, R23.2
unnamed: C15.2, R26.1
unnamed: C16.1, R27.2
unnamed: C17.1, R30.1, U2.5 (+)
unnamed: C17.2, U2.1, U2.2 (-)
unnamed: D1.2 (A), R6.2
unnamed: D2.1 (K), R7.1
unnamed: J5.4, R28.1, U2.3 (+)
unnamed: J8.1, R29.2
unnamed: R1.2, R2.1, SW1.5
unnamed: R2.2, R3.1, SW1.4
unnamed: R3.2, R4.1, SW1.3
unnamed: R4.2, R5.1, SW1.2, U1.5 (+)
unnamed: R8.1, RV2.1, RV2.2
unnamed: R8.2, R9.1, U3.3 (+)
unnamed: R10.1, R11.2, U4.3 (+)
unnamed: R10.2, U5.4 (VP)
unnamed: R12.1, RV6.1
unnamed: R12.2, U5.1 (Scale1)
unnamed: R13.1, R14.2, RV6.2, RV6.3, U5.3 (VEE)
unnamed: R13.2, U5.2 (Scale2)
unnamed: R15.1, RV7.3
unnamed: R15.2, R16.2, R19.1, R20.1, R21.1, R22.1, R23.1, U5.15 (VFCI)
unnamed: R16.1, RV5.2
unnamed: R17.1, R18.1, U4.6 (-)
unnamed: R22.2, RV8.2
unnamed: R24.2, U5.14 (VS)
unnamed: R25.2, R26.2, R27.1, U5.13 (VLFI)
unnamed: R29.1, U2.6 (-), U2.7
unnamed: RV1.3, TP2.1, U1.6 (-), U1.7
unnamed: RV3.2, U3.5 (+)
unnamed: RV4.1, U3.6 (-), U3.7
unnamed: RV4.2, U5.5 (VPWM)
unnamed: RV5.3, U5.7 (VHFT)
unnamed: SW1.1, SW1.6, U1.3 (+)
unnamed: U4.5 (+), U5.10 (VTO)
OCTAVE: R21.2, TP3.1, U1.1, U1.2 (-)
PULSE: J5.3, U4.1, U4.2 (-)
PWM: J3.1, RV4.3
SAW: J5.2, U5.8 (VSO)
SOFT_SYNC: C13.1, J4.3
TRIANGLE: J5.1, R17.2, U4.7

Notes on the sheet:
Multi-turn
0-4.2V
MOD
CV Adjust
Scale Adjust
High Freq Track
PWM
Pulse Width

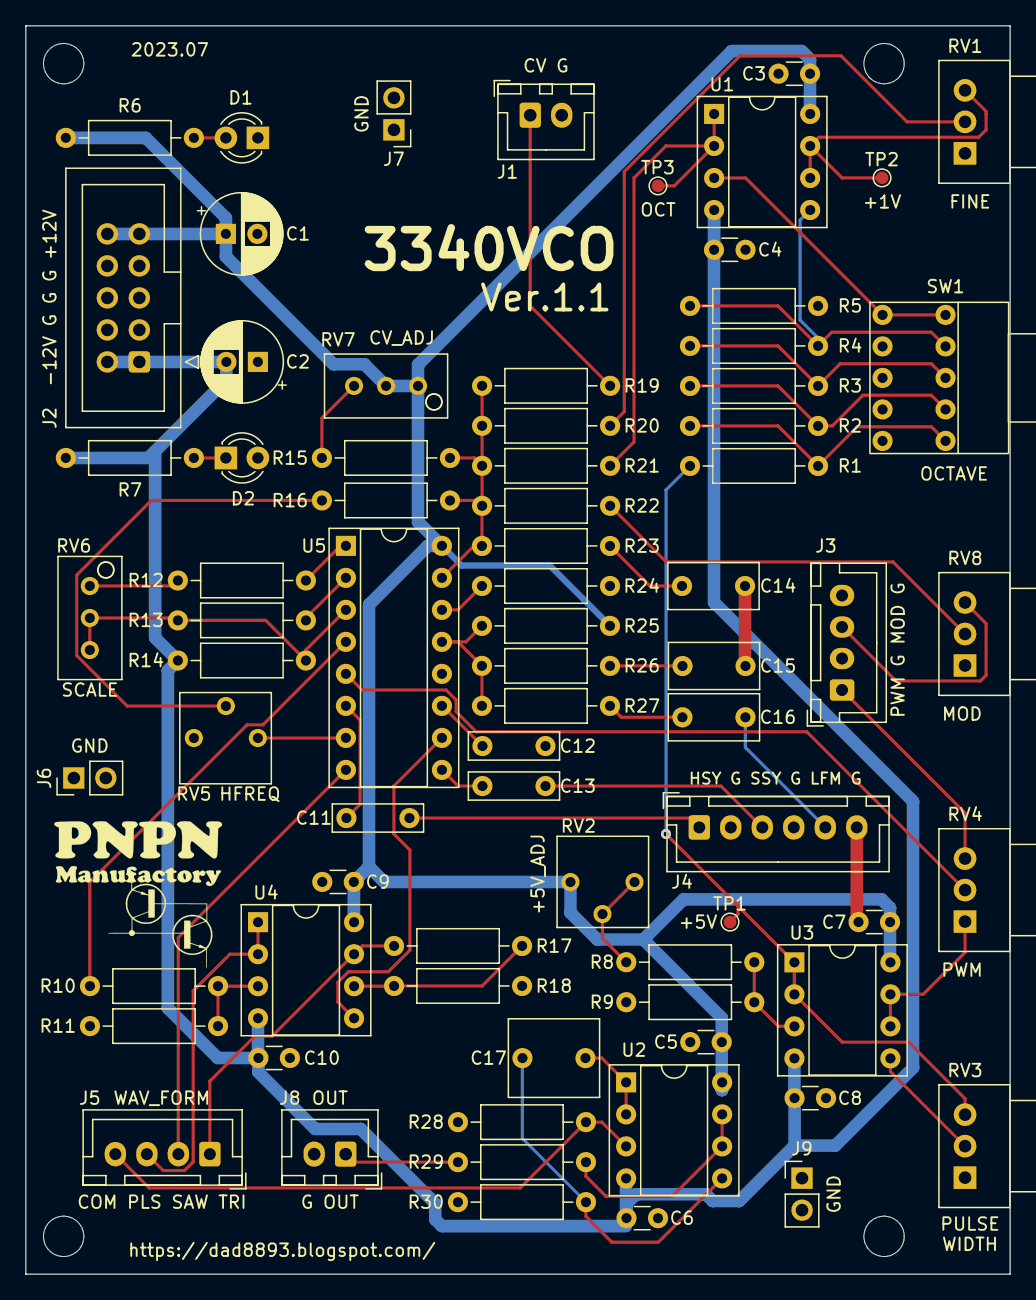
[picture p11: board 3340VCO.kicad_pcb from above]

Board: 2 copper layers, 78.1 x 99.1 mm, 79 parts (0 on the bottom side), 54 nets.

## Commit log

2023-07-17 部品配置
    [3340VCO.kicad_pcb, 3340VCO.kicad_sch]
2023-07-27 基板製造
    [3340VCO-B_Cu.gbl, 3340VCO-B_Mask.gbs, 3340VCO-B_Paste.gbp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]
2023-08-14 '23夏コミケ
    [3340VCO-B_Cu.gbl, 3340VCO-B_Mask.gbs, 3340VCO-B_Paste.gbp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]
2023-08-25 EXT Panel
    [3340VCO_panel_EXT.dwg, CV_Frequency.xlsx]
2023-11-07 マニュアルを追加
